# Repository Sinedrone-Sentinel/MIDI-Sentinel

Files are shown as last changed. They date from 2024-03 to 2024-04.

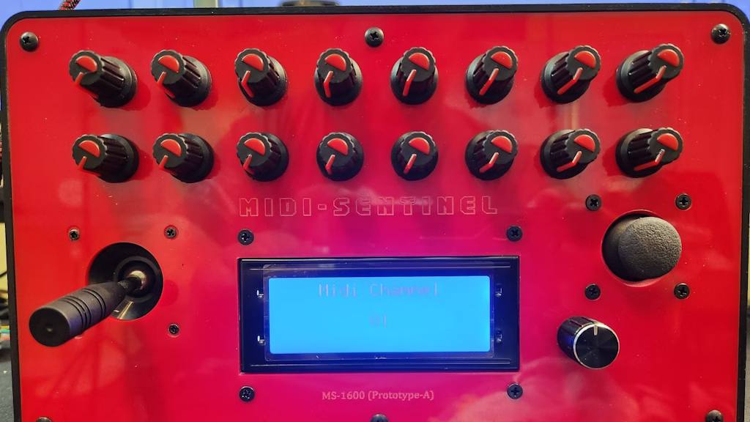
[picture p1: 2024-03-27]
Images/Original Prototype.png

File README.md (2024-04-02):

This is the Midi-Sentinel Project

A midi controller with BOTH a joystick AND a thumbstick.
However, you are not limited to JUST these 2 XY controls.
You can have 2 Joysticks, or 2 thumbsticks or any combination
that you wish. You only need to modify the project to your needs.

BEFORE YOU START BUYING PARTS
The LCD screen and the Mainboard ARE DIFFERENT SIZES on 
prototype B than they are on prototype A. Make sure that the
filename prefixes MATCH in your LOCAL folder copy before you
start spending money!

In the DIY section, you will find "How-To" guides to build the
Midi Sentinel, step-by-step for each version of the Midi-Sentinel.
Along with separate parts lists for each version that includes
the original purchase source. (No guarantee that any particular
part will still be in stock on sites listed.)

In the Images section, you will find pictures of the different
versions so you know what you are looking for in the other sections.

In the CAD section, you will find the files for the early prototype
and the final Kickstarter version. The early kickstarter version
will be cheaper to make considering that the enclosure used was
NOT a custom designed enclosure, but an off the shelf enclosure
that you can buy online for around $20.
Also, worth noting. If you buy the "Off-the-shelf" enclosure, there
is NO usb mounting "hole" on the back. You will either need to cut
that out yourself or the website where it is sold has a fairly cheap
machining option where they will modify it for you before shipping.

In the EDA section, you will find the mainboard circuit board design
file and the knob controller circuit board file.  These can be uploaded
as they are to sites like PCBWay.com to be manufactured for about $5
per board. (Be aware though, PCBWay has a 5 board minimum per schematic.)

If you are here, it is because you are interested in either building
your own (DIY kit or self sourcing parts) or you want to modify the
one you have. Either way here is a short list of basic tools and
items that you should have before you start.

Soldering Iron, Solder, Flux pen or paste, spare wire, multimeter,
philips head screw driver, wire cutters, wire brush (for cleaning soldering iron)

Other tools may be required depending on what you are attempting.

Software needed, Arduino IDE.

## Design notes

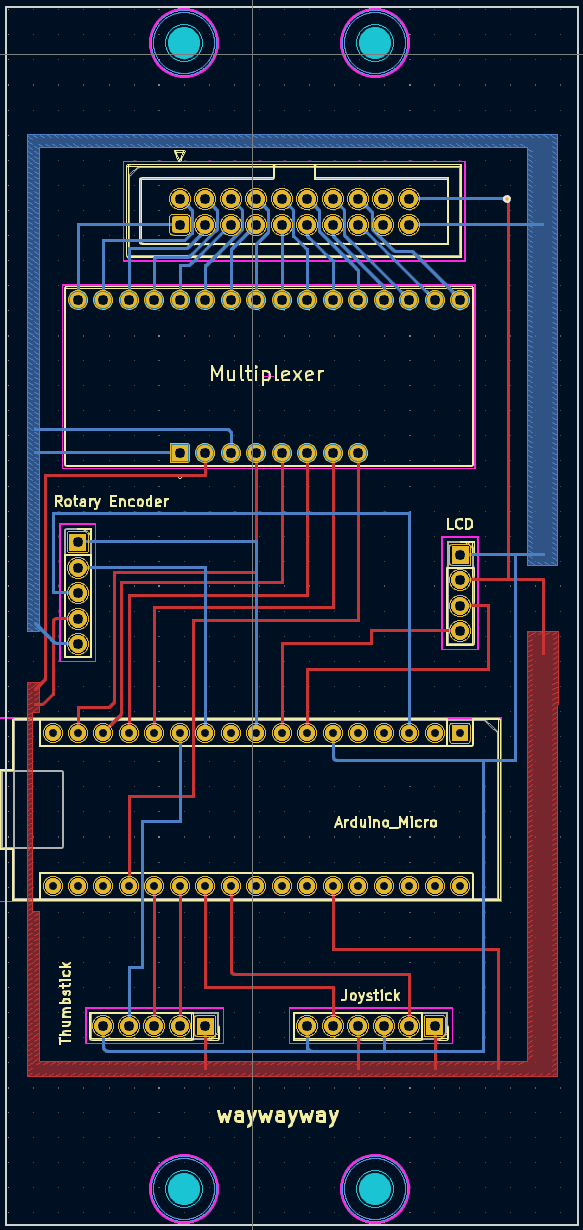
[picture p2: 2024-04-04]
Images/Main-Board_A.PNG

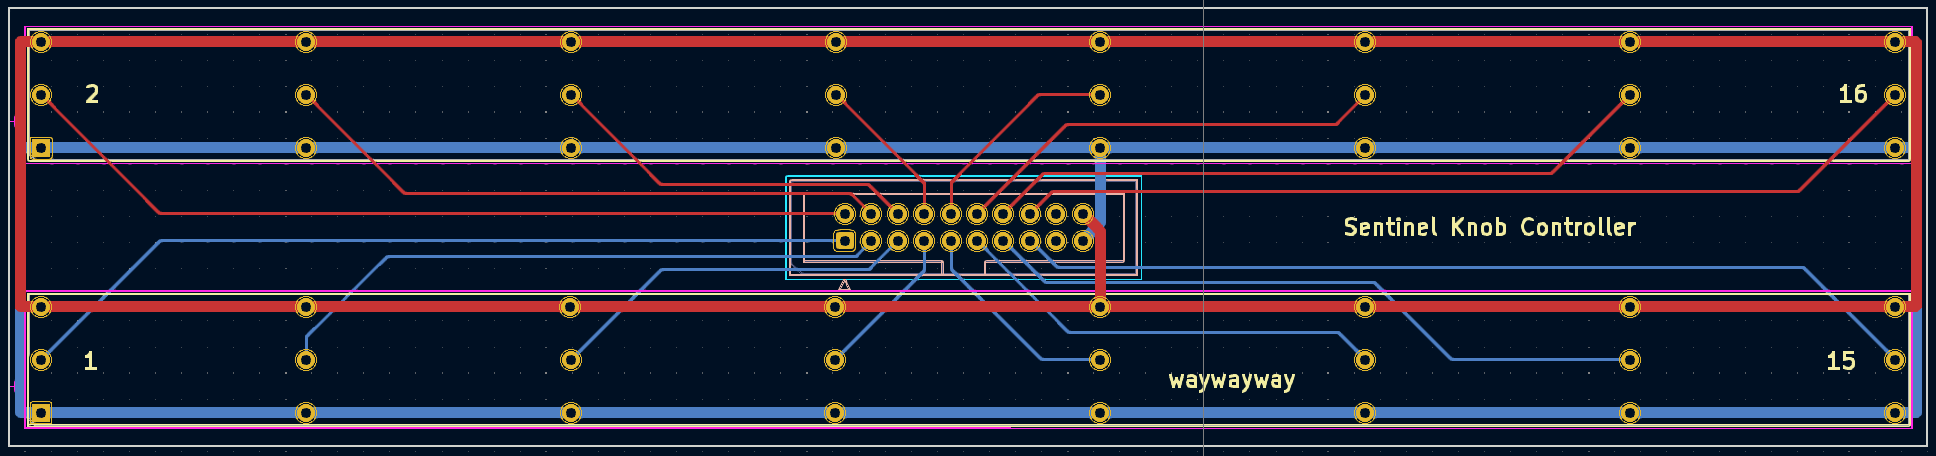
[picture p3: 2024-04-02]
Images/Controller-Board.PNG

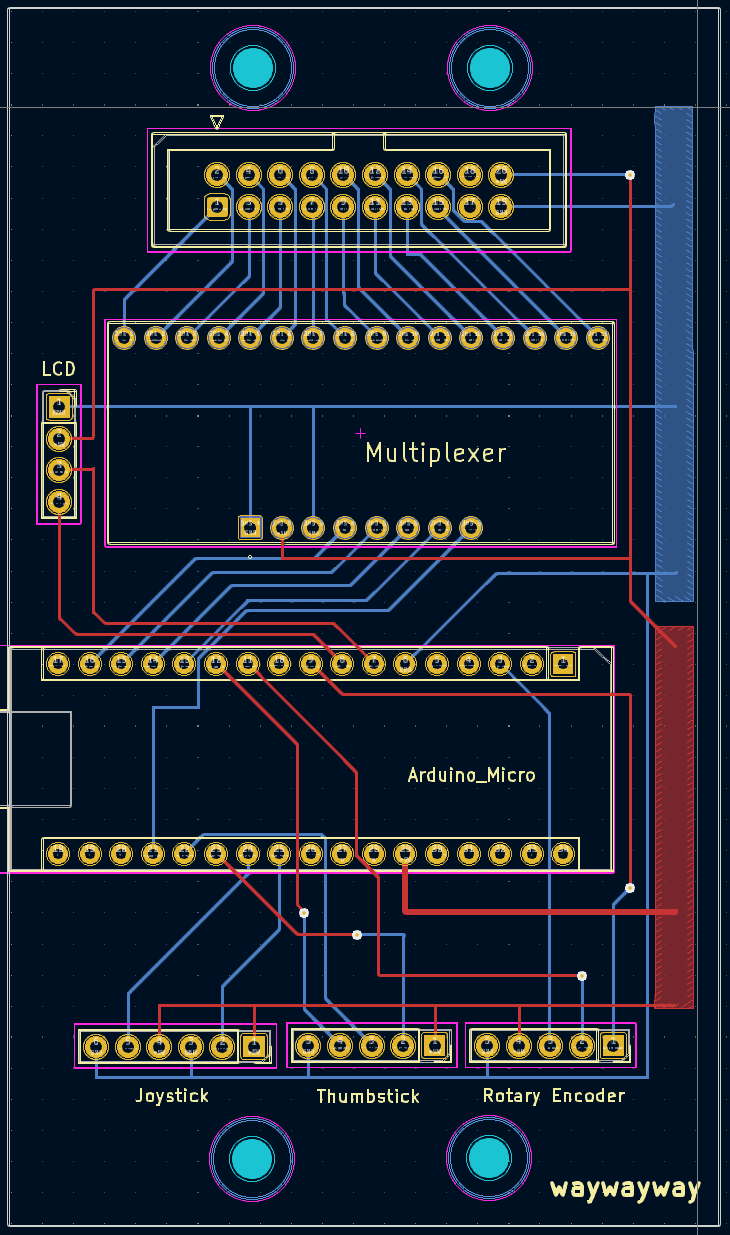
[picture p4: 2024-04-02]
Images/Main-Board_B.PNG

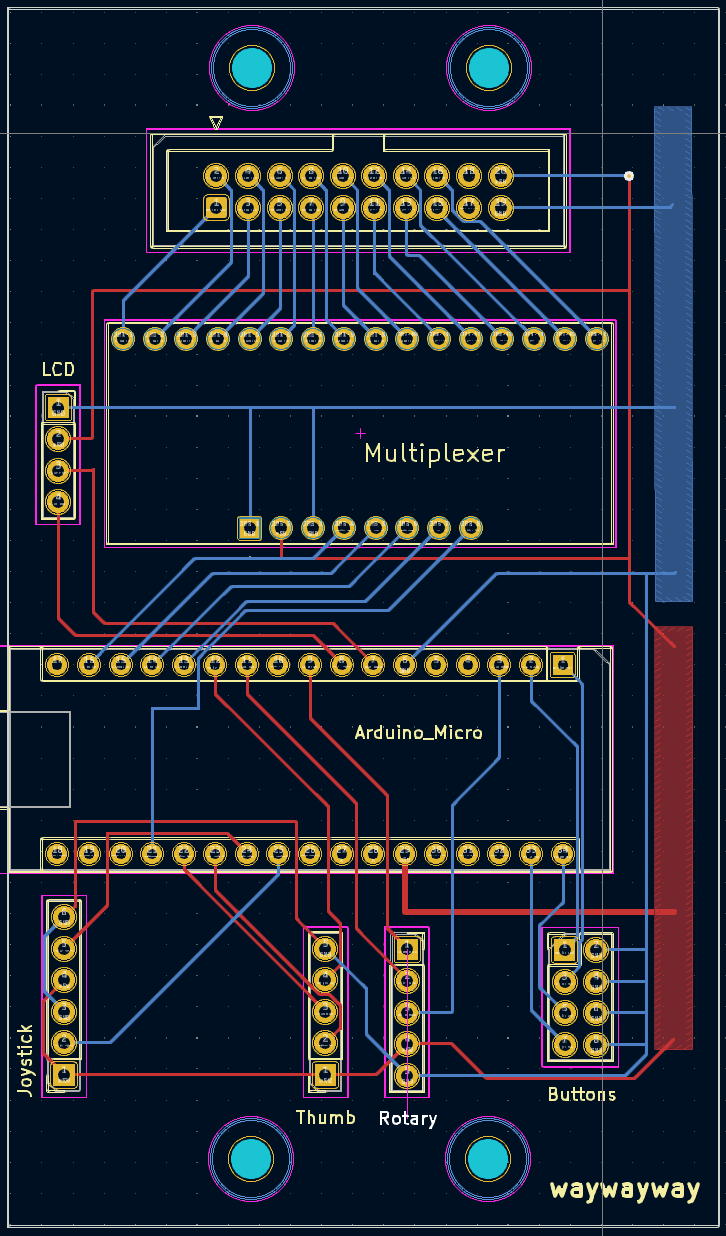
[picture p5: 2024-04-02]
Images/Main-Board_C.PNG

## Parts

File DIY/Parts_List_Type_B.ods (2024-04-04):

QTY | Name | Source
1 | Arduino Micro | https://www.amazon.com/Arduino-Micro-Headers-A000053-Controller/dp/B00AFY2S56
1 | 4067 Multiplexer | https://www.amazon.com/HiLetgo-CD74HC4067-Channel-Multiplexer-Breakout/dp/B01DLHKLNE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
1 | 16x2 I2C LCD | https://www.amazon.com/Hosyond-Display-Module-Arduino-Raspberry/dp/B0BWTFN9WF
1 | Analog Joystick | https://www.adafruit.com/product/3102
1 | Thumbstick | https://www.adafruit.com/product/512
1 | KY-040 Rotary Encoder | https://www.amazon.com/HiLetgo-Backlight-Display-Arduino-MEGA2560/dp/B01DKETWO2?sp_csd=d2lkZ2V0TmFtZT1zcF9hdGY
16 | 10K Linear Potentiometers | https://www.taydaelectronics.com/potentiometer-variable-resistors/rotary-potentiometer/linear/tayda-b-10k-ohm-linear-taper-potentiometer-spline-shaft-pc-mount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
16 | Knobs | https://www.taydaelectronics.com/potentiometer-variable-resistors/knobs/black-plastic-knob-with-red-pointer.html
1 | Project Enclosure | https://github.com/Sinedrone-Sentinel/MIDI-Sentinel/blob/main/CAD%20Files/ProtoType_B_Enclosure.sat
1 | USB Type B cable | https://www.amazon.com/Amazon-Basics-External-Gold-Plated-Connectors/dp/B00NH13DV2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
1 | USB Type B to Micro Mount | https://www.digikey.com/en/products/detail/sparkfun-electronics/CAB-15463/10819707?gad_source=1
1 | Main-Board Type A | https://github.com/Sinedrone-Sentinel/MIDI-Sentinel/tree/main/EDA%20Files/Main-Board
1 | Controller Board | https://github.com/Sinedrone-Sentinel/MIDI-Sentinel/tree/main/EDA%20Files/Knob-Mount
1 | 4" – 6" IDC Ribbon Cable | https://www.amazon.com/Connectors-Pro-Connector-Conductors-20P-FF-15CM-2PK/dp/B0CSB6RTFC
2 | 20Pin Box Header IDC Socket Straight Male Connectors | https://www.amazon.com/Uxcell-a14112600ux0302-2-54mm-Straight-Connector/dp/B00VGDRKYO
1 | Front Panel Type A | https://github.com/Sinedrone-Sentinel/MIDI-Sentinel/blob/main/CAD%20Files/Front%20Panel%20Proto-A.dxf
20 | 15 CM female to female Jumper Wires | https://www.amazon.com/California-JOS-Breadboard-Optional-Multicolored/dp/B0BRTJQGS6
4 | Rubber Feet | https://www.amazon.com/Super-Soft-Round-Rubber-Feet/dp/B00S47D52G?sp_csd=d2lkZ2V0TmFtZT1zcF9tdGY
4 | #10 Screws 1/4" long | https://www.amazon.com/Phillips-Stainless-Tapping-SG-TZH/dp/B0B2L7GYDS?sp_csd=d2lkZ2V0TmFtZT1zcF9hdGY
44 | Header Pins | https://www.amazon.com/HiLetgo-20pcs-2-54mm-Single-Header/dp/B07R5QDL8D?sp_csd=d2lkZ2V0TmFtZT1zcF9hdGY
8 | Stand-Offs (6+6mm style) | https://www.amazon.com/uxcell-Male-Female-Motherboard-Standoff-Quadcopter/dp/B08F2DH994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
14 | M3 - 0.5 x 8 screws | https://www.amazon.com/iExcell-Socket-Button-Screws-Finish/dp/B08R379Z1C
4 | 3/8" flat head wood screws | https://www.amazon.com/Stainless-Phillips-Screw-Bolt-Dropper/dp/B079Y9KW9S?pid=v9zFyf4&s=industrial

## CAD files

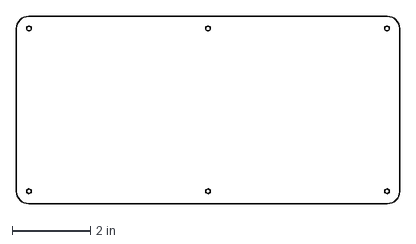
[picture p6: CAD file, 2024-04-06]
CAD Files/Prototype-B_Blank.dxf
9.81 x 4.80 in

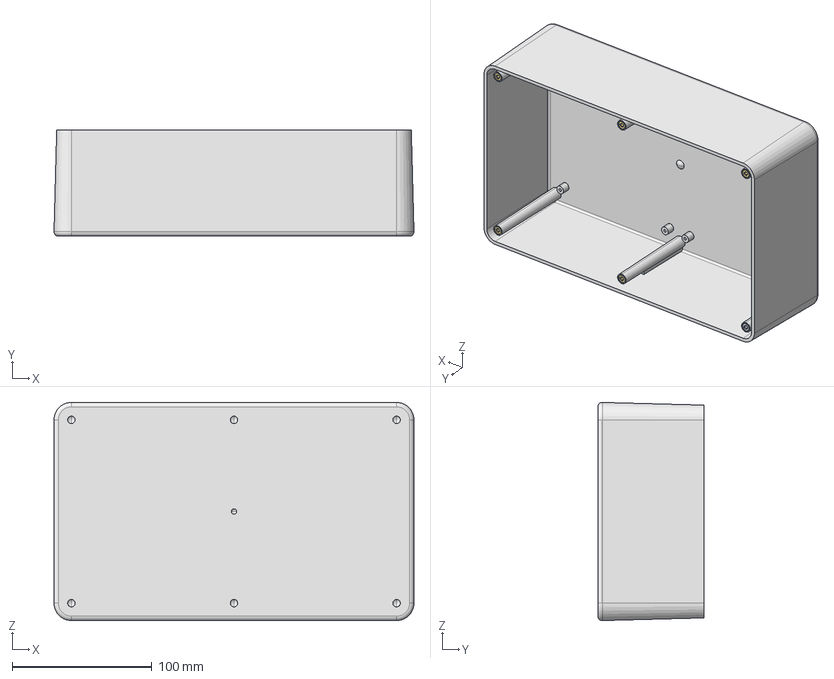
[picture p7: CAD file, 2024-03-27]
CAD Files/ProtoType_A_Enclosure.step
257.8 x 76.2 x 156.2 mm

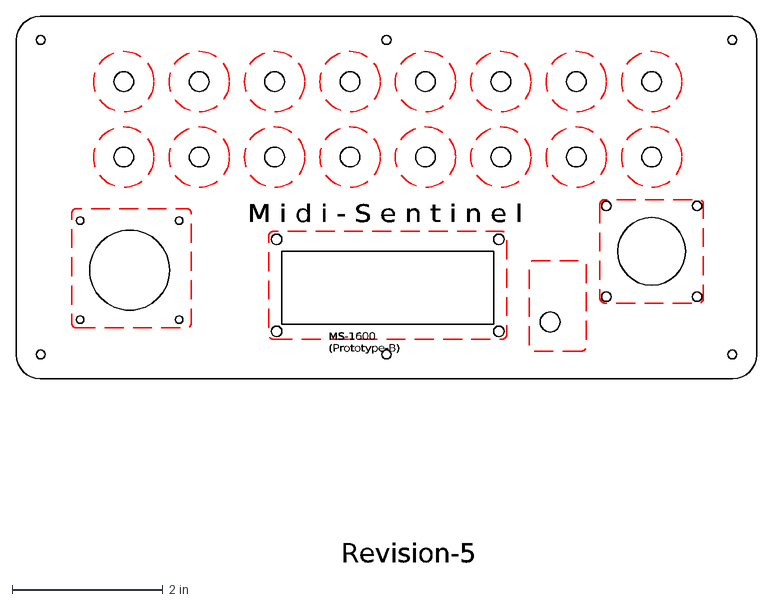
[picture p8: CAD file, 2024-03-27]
CAD Files/Front Panel Proto-B.dxf
Revision-5
M i d i - S e n t i n e l
MS-1600 (Prototype-B)

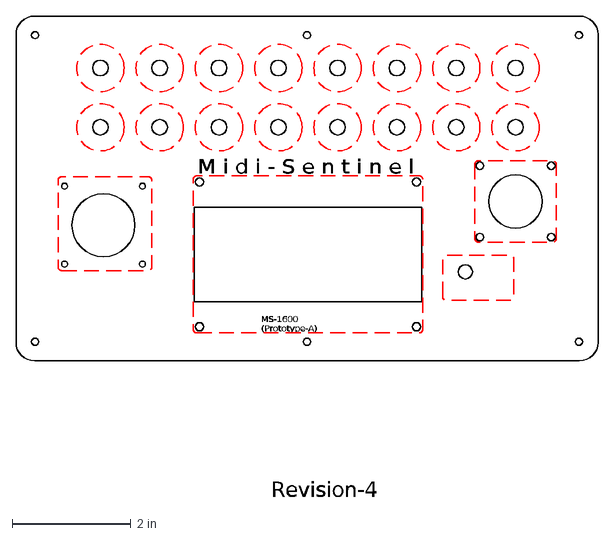
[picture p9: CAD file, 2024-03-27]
CAD Files/Front Panel Proto-A.dxf
Revision-4
M i d i - S e n t i n e l
MS-1600 (Prototype-A)

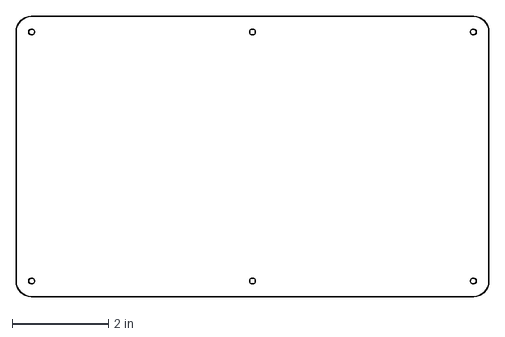
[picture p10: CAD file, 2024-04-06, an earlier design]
CAD Files/Prototype-A_Blank.dxf
9.81 x 5.81 in

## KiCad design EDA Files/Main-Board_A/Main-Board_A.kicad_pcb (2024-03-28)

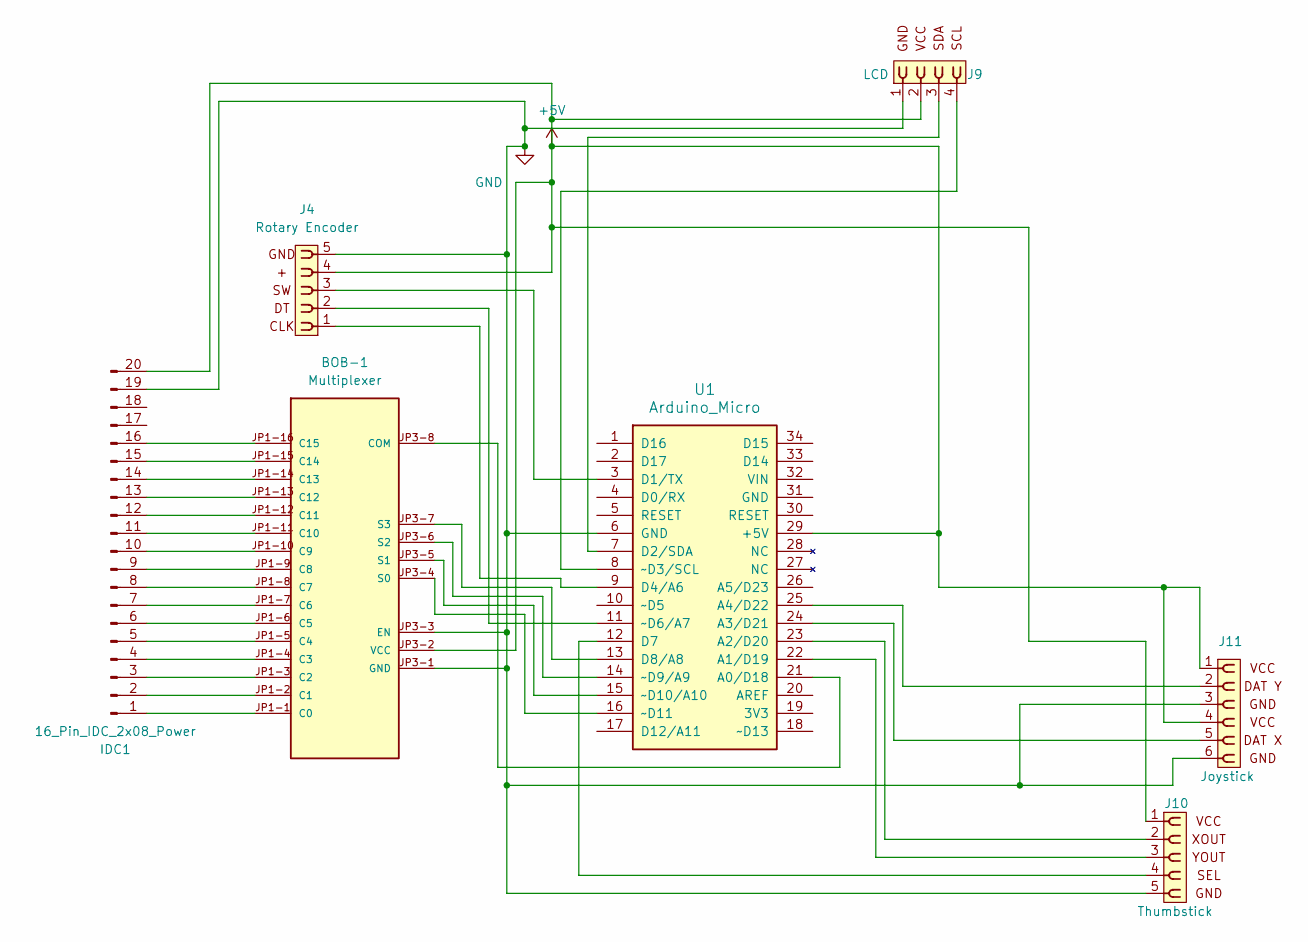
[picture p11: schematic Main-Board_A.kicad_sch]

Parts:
BOB-1: Multiplexer; BOB-09056; PARTREV v11
IDC1: 16_Pin_IDC_2x08_Power; IDC-Header_2x10_P2.54mm_Vertical
J4: Rotary Encoder; PinSocket_1x05_P2.54mm_Vertical
J9: LCD; PinSocket_1x04_P2.54mm_Vertical
J10: Thumbstick; PinSocket_1x05_P2.54mm_Vertical
J11: Joystick; PinSocket_1x06_P2.54mm_Vertical
U1: Arduino_Micro

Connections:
+5V: BOB-1.JP3-2 (VCC), IDC1.20, J4.4, J9.2, J10.1, J11.1, J11.4, U1.29 (+5V)
GND: BOB-1.JP3-1 (GND), BOB-1.JP3-3 (EN), IDC1.19, J4.5, J9.1, J10.5, J11.3, J11.6, U1.6 (GND)
unnamed: BOB-1.JP1-1 (C0), IDC1.1
unnamed: BOB-1.JP1-2 (C1), IDC1.2
unnamed: BOB-1.JP1-3 (C2), IDC1.3
unnamed: BOB-1.JP1-4 (C3), IDC1.4
unnamed: BOB-1.JP1-5 (C4), IDC1.5
unnamed: BOB-1.JP1-6 (C5), IDC1.6
unnamed: BOB-1.JP1-7 (C6), IDC1.7
unnamed: BOB-1.JP1-8 (C7), IDC1.8
unnamed: BOB-1.JP1-9 (C8), IDC1.9
unnamed: BOB-1.JP1-10 (C9), IDC1.10
unnamed: BOB-1.JP1-11 (C10), IDC1.11
unnamed: BOB-1.JP1-12 (C11), IDC1.12
unnamed: BOB-1.JP1-13 (C12), IDC1.13
unnamed: BOB-1.JP1-14 (C13), IDC1.14
unnamed: BOB-1.JP1-15 (C14), IDC1.15
unnamed: BOB-1.JP1-16 (C15), IDC1.16
unnamed: BOB-1.JP3-8 (COM), U1.21 (A0/D18)
unnamed: BOB-1.JP3-4 (S0), U1.16 (~D11)
unnamed: BOB-1.JP3-5 (S1), U1.15 (~D10/A10)
unnamed: BOB-1.JP3-6 (S2), U1.14 (~D9/A9)
unnamed: BOB-1.JP3-7 (S3), U1.13 (D8/A8)
unnamed: J10.3, U1.22 (A1/D19)
unnamed: J10.2, U1.23 (A2/D20)
unnamed: J11.5, U1.24 (A3/D21)
unnamed: J11.2, U1.25 (A4/D22)
unnamed: J4.3, U1.3 (D1/TX)
unnamed: J9.3, U1.7 (D2/SDA)
unnamed: J4.1, U1.9 (D4/A6)
unnamed: J10.4, U1.12 (D7)
unnamed: J9.4, U1.8 (~D3/SCL)
unnamed: J4.2, U1.11 (~D6/A7)

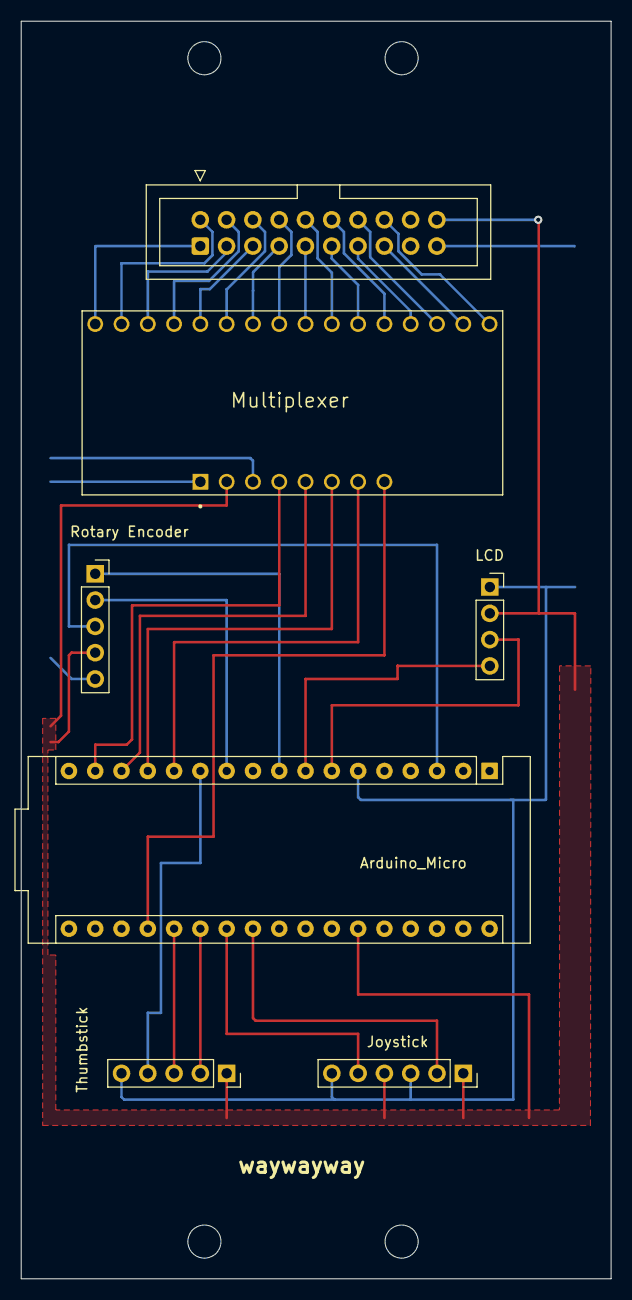
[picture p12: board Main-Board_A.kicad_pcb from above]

Board: 2 copper layers, 57.0 x 121.5 mm, 7 parts (0 on the bottom side), 33 nets.

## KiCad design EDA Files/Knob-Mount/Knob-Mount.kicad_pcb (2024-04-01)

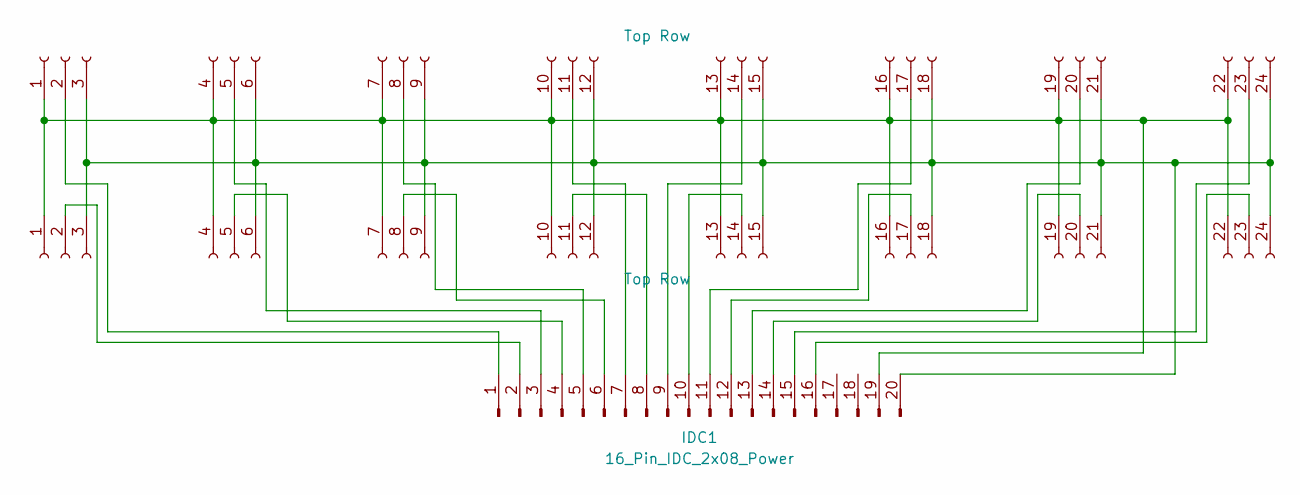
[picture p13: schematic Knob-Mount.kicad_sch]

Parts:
IDC1: 16_Pin_IDC_2x08_Power; IDC-Header_2x10_P2.54mm_Vertical
J1, J2: Top Row; PinHeader_8x3_P2.54mm_Knobs

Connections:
unnamed: IDC1.1, J1.2
unnamed: IDC1.2, J2.2
unnamed: IDC1.3, J1.5
unnamed: IDC1.4, J2.5
unnamed: IDC1.5, J1.8
unnamed: IDC1.6, J2.8
unnamed: IDC1.7, J1.11
unnamed: IDC1.8, J2.11
unnamed: IDC1.9, J1.14
unnamed: IDC1.10, J2.14
unnamed: IDC1.11, J1.17
unnamed: IDC1.12, J2.17
unnamed: IDC1.13, J1.20
unnamed: IDC1.14, J2.20
unnamed: IDC1.15, J1.23
unnamed: IDC1.16, J2.23
unnamed: IDC1.19, J1.1, J1.4, J1.7, J1.10, J1.13, J1.16, J1.19, J1.22, J2.1, J2.4, J2.7, J2.10, J2.13, J2.16, J2.19, J2.22
unnamed: IDC1.20, J1.3, J1.6, J1.9, J1.12, J1.15, J1.18, J1.21, J1.24, J2.3, J2.6, J2.9, J2.12, J2.15, J2.18, J2.21, J2.24

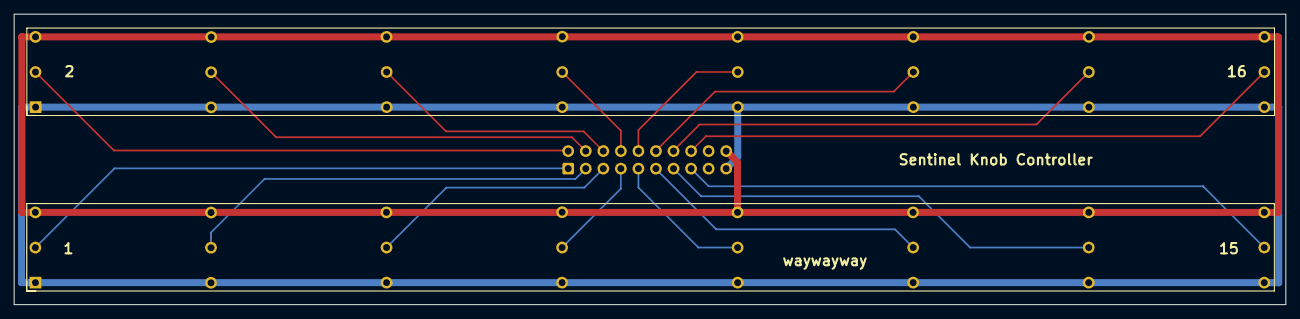
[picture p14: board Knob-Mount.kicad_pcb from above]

Board: 2 copper layers, 184.0 x 42.0 mm, 3 parts (1 on the bottom side), 18 nets.

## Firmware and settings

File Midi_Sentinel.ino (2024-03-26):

#include <LiquidCrystal_I2C.h>
#include <MIDIUSB.h>
#include <ResponsiveAnalogRead.h>
#include <CD74HC4067.h>
#include <KY040rotary.h>
#include <Bounce2.h>

#define N_POTS 16  //total number of pots across all muxes
//* Define s0, s1, s2, s3, and x pins
#define s0 11
#define s1 10
#define s2 9
#define s3 8
#define x1 A0  // analog pin of the first mux

#define CLK 4  //Rotary encoder
#define DT 6
#define SW 1

//#define thumbSwitch 7  //thumbstick click
#define jStickX A3
#define jStickY A4
#define thumbX A2
#define thumbY A1
#define thumbSwitch 7

byte stickCtrlX = 17;
byte stickCtrlY = 18;
byte thumbCtrlX = 19;   //Control Number
byte thumbCtrlY = 20;   //"            "
byte midiChannel = 1;   // Set your desired MIDI channel
byte midiPChannel = 0;  // Keep track for display refresh reasons

volatile bool btnPressed = false;   //rotary encoder btn
volatile bool btnPressed2 = false;  //thumbstick btn
bool btnPVal = false;
bool btnPVal2 = false;

float snapMultiplier = 0.10;  // (0.0 - 1.0) - Increase for faster, but less smooth reading

int stickState[4] = { 0 };
int stickPState[4] = { 0 };
int potState[N_POTS] = { 0 };   // Current state of the pot
int potPState[N_POTS] = { 0 };  // Previous state of the pot
bool thumbChanged = false;      // thumbstick has moved

/////////////////////////////////////////////
//Obj Inits
CD74HC4067 mux = CD74HC4067(s0, s1, s2, s3);
LiquidCrystal_I2C lcd(0x27, 20, 4);
Bounce myClick = Bounce();   //debounce for rotary encoder click
Bounce myClick2 = Bounce();  //debounce for thumbstick click

KY040 myEncoder(CLK, DT, SW);
const byte N_POTS_PER_MUX = 16;                                                                     // Number of pots connected to the multiplexer
const byte POT_MUX_PIN[N_POTS_PER_MUX] = { 0, 1, 2, 3, 4, 5, 6, 7, 8, 9, 10, 11, 12, 13, 14, 15 };  // Channels on the multiplexer

ResponsiveAnalogRead responsivePots[N_POTS_PER_MUX] = {
  ResponsiveAnalogRead(x1, true),
  ResponsiveAnalogRead(x1, true),
  ResponsiveAnalogRead(x1, true),
  ResponsiveAnalogRead(x1, true),
  ResponsiveAnalogRead(x1, true),
  ResponsiveAnalogRead(x1, true),
  ResponsiveAnalogRead(x1, true),
  ResponsiveAnalogRead(x1, true),
  ResponsiveAnalogRead(x1, true),
  ResponsiveAnalogRead(x1, true),
  ResponsiveAnalogRead(x1, true),
  ResponsiveAnalogRead(x1, true),
  ResponsiveAnalogRead(x1, true),
  ResponsiveAnalogRead(x1, true),
  ResponsiveAnalogRead(x1, true),
  ResponsiveAnalogRead(x1, true)
};
ResponsiveAnalogRead responsiveThumb[2] = {
  ResponsiveAnalogRead(thumbX, true),
  ResponsiveAnalogRead(thumbY, true)
};
ResponsiveAnalogRead responsiveStick[2] = {
  ResponsiveAnalogRead(jStickX, true),
  ResponsiveAnalogRead(jStickY, true)
};

void potentiometers() {
  for (int i = 0; i < N_POTS_PER_MUX; i++) {
    mux.channel(POT_MUX_PIN[i]);
    delayMicroseconds(8);  // Short delay to allow the analog signal to settle
    int rawReading = analogRead(x1);
    responsivePots[i].update(rawReading);

    int newState = map(responsivePots[i].getValue(), 0, 1023, 0, 127);
    if (potPState[i] != newState) {
      potState[i] = newState;
      Serial.println(potState[i]);
      controlChange(midiChannel - 1, i, potState[i]);
      MidiUSB.flush();
      potPState[i] = potState[i]; // Update the previous state after sending MIDI message
    }
  }
}

void MidiDown() {
  if (btnPressed == true) {

    if (midiChannel == 1) {
      midiChannel = 16;
    } else {
      midiChannel--;
    }
    //Serial.println("Midi Channel Changed Down");
  }
}

void MidiUp() {
  if (btnPressed == true) {
    if (midiChannel == 16) {
      midiChannel = 1;
    } else {
      midiChannel++;
    }
    //Serial.println("Midi Channel Changed Up");
  }
}

void setup() {
  Serial.begin(115200);
  pinMode(x1, INPUT);
  pinMode(thumbX, INPUT);
  pinMode(thumbY, INPUT);
  pinMode(jStickX, INPUT);
  pinMode(jStickY, INPUT);
  pinMode(thumbSwitch, INPUT_PULLUP);
  pinMode(SW, INPUT_PULLUP);

  myClick.attach(SW);
  myClick.interval(50);  // interval in ms
  myClick.update();

  myClick2.attach(thumbSwitch);
  myClick2.interval(50);
  myClick2.update();

  myEncoder.OnButtonLeft(MidiDown);
  myEncoder.OnButtonRight(MidiUp);

  for (int i = 0; i < N_POTS_PER_MUX; i++) {
    responsivePots[i].enableEdgeSnap();
    responsivePots[i].setSnapMultiplier(snapMultiplier);
  }

  for (int i = 0; i < 2; i++) {
    responsiveThumb[i].enableEdgeSnap();
    responsiveThumb[i].setSnapMultiplier(snapMultiplier);
  }

  for (int i = 0; i < 2; i++) {
    responsiveStick[i].enableEdgeSnap();
    responsiveStick[i].setSnapMultiplier(snapMultiplier);
  }

  lcd.init();
  lcd.backlight();
  lcd.setCursor(0, 1);
  lcd.print("MIDI Sentinel Online");
  delay(4000);
  lcd.clear();
  lcdPrint();
}

void interruptFunction() {

  if (btnPressed == true) {
    btnPVal = true;
    btnPressed = false;
  } else {
    btnPVal = false;
    btnPressed = true;
  }
  //Serial.println(btnPressed);
  return;
}

void interruptFunction2() {

  if (btnPressed2 == true) {
    btnPVal2 = true;
    btnPressed2 = false;
  } else {
    btnPVal2 = false;
    btnPressed2 = true;
  }
  return;
}

void controlChange(byte channel, byte control, byte value) {
  midiEventPacket_t event = { 0x0B, 0xB0 | channel, control, value };
  //Serial.println(String(channel) + " " + String(control) + " " + String(value));
  MidiUSB.sendMIDI(event);
}

void Sticks() {
  // Define a threshold for movement detection
  const int movementThreshold = 5; // Adjust this value as needed

  // Thumbstick handling
  if (btnPressed2 == true) {
    //get current thumbstick position and hold
  } else if (btnPressed2 == false) {
    // Thumbstick live tracking
    int rawReading1 = analogRead(thumbX);
    int rawReading2 = analogRead(thumbY);

    responsiveThumb[0].update(rawReading1);
    responsiveThumb[1].update(rawReading2);

    int newStateX = map(responsiveThumb[0].getValue(), 0, 1023, 0, 127);
    int newStateY = map(responsiveThumb[1].getValue(), 0, 1023, 0, 127);

    if (abs(newStateX - stickPState[0]) > movementThreshold) {
      controlChange(midiChannel - 1, thumbCtrlX, newStateX);
      MidiUSB.flush();
      stickPState[0] = newStateX;
    }
    if (abs(newStateY - stickPState[1]) > movementThreshold) {
      controlChange(midiChannel - 1, thumbCtrlY, newStateY);
      MidiUSB.flush();
      stickPState[1] = newStateY;
    }
  }

  // Joystick handling
  int rawReading3 = analogRead(jStickX);
  int rawReading4 = analogRead(jStickY);

  responsiveStick[0].update(rawReading3);
  responsiveStick[1].update(rawReading4);

  int newStateX = map(responsiveStick[0].getValue(), 0, 1023, 0, 127);
  int newStateY = map(responsiveStick[1].getValue(), 0, 1023, 0, 127);

  if (abs(newStateX - stickState[2]) > movementThreshold) {
    controlChange(midiChannel - 1, stickCtrlX, newStateX);
    MidiUSB.flush();
    stickState[2] = newStateX;
  }
  if (abs(newStateY - stickState[3]) > movementThreshold) {
    controlChange(midiChannel - 1, stickCtrlY, newStateY);
    MidiUSB.flush();
    stickState[3] = newStateY;
  }
}

void loop() {
  myEncoder.Process(millis());

  myClick2.update();
  if (myClick2.fell()) {
    interruptFunction2();
  }

  myClick.update();
  if (myClick.fell()) {
    interruptFunction();
  }

  potentiometers();
  Sticks();

  if (btnPressed == true) {
    lcdPrint();
  }
}

void lcdPrint() {

  if (btnPressed == true) {
    lcd.setCursor(7, 2);
    lcd.print("-=");
    lcd.setCursor(11, 2);
    lcd.print("=-");
  }
  lcd.setCursor(4, 0);
  lcd.print("Midi Channel");
  lcd.setCursor(7, 2);

  //add code this line to determine single or double digit
  if (midiChannel < 10) {
    lcd.print("  0" + String(midiChannel) + "  ");
  } else {
    lcd.print("  " + String(midiChannel) + "  ");
  }
  //Serial.println(midiChannel);
  midiPChannel = midiChannel;
  //}
}

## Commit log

2024-03-26 Added Original Code File
    Original Midi-Sentinel Release Code. 16 knobs on a multiplexer, using an Arduino Micro, with a joystick, thumbstick, 16x2 LCD and push button rotary encoder.
2024-03-26 EDA Files
    Main Board and controller board designs
    [MIDI Sentinel.kicad_pcb, MIDI Sentinel.kicad_sch]
2024-03-26 EDA Upload
    [Knob-Mount.kicad_pcb, Knob-Mount.kicad_sch, MIDI Sentinel.kicad_pcb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]
2024-03-27 Product Type A
    Upload of Original Prototype Image
2024-03-27 Product Images
    Various Prototype and Product Images
2024-03-27 added panels
    A and B panels
    [Front Panel Proto-A.dxf, Front Panel Proto-B.dxf]
2024-03-27 Cad Files
    Enclosures for both prototypes
    [ProtoType_A_Enclosure.step]
2024-03-31 update lists
    [Parts_List_Type_A.ods]
2024-04-04 Parts lists update
    [Parts_List_Type_B.ods]
2024-04-04 Complete EDA Update
    [BOM_Knob-Mount.kicad_pcb.xls, BOM_MIDI Sentinel.kicad_pcb.xls, Main-Board_A.kicad_pcb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]
2024-04-04 PCBWAY zip files added
2024-04-05 Revert "Applied license and added copyright info"
    [Midi_Sentinel.ino]
2024-04-06 Front Panel Blanks
    [Prototype-A_Blank.dxf, Prototype-B_Blank.dxf]
